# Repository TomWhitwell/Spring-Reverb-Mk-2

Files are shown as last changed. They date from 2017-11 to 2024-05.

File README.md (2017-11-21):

## Spring Reverb Mk 2

These are the design files for the Music Thing Modular Spring Reverb. 

[Full details about the module are in this rather long Medium post](https://medium.com/music-thing-modular-notes/everything-i-know-about-spring-reverb-1fb4b32abf87) 

You can [buy full kits for the Spring module here at Thonk](https://www.thonk.co.uk/shop/mtm-spring-reverb-mkii-kit/?utm_source=github), and [here's the kit for the expander](https://www.thonk.co.uk/shop/mtm-spring-expander-kit/?utm_source=github). 

# Issues and troubleshooting 
The quickest way to find solutions or report issues is [here in the issue log](https://github.com/TomWhitwell/Spring-Reverb-Mk-2/issues)

# In this repository you will find: 

[The Schematic PDF is here](https://github.com/TomWhitwell/Spring-Reverb-Mk-2/raw/master/Collateral/SpringReverbMk2-Schematic.pdf) 

Eagle CAD PCB files for:  
1. The main module, which contains two PCBs in the same file: SpringReverbRev2_combined
2. A plain PCB panel for the main module: SpringReverbRev2_panel
3. The PCB for the expander: Spring_Rev2_expander
4. A plan PCB panel for the expander: Spring_Rev2_expander_panel

The draft BOM is [here on google drive](https://docs.google.com/spreadsheets/d/1CzZeQc7hFVf5DQ_6vUL5soYb9Bh4oqvPB2Zx_D7NQ_I/edit?usp=sharing)

# License

Spring is Open Hardware
All hardware and software design in this project is Creative Commons licensed by Tom Whitwell: CC-BY-SA: Attribution / ShareAlike
If you use any work in this project, you should credit me, and you must republish any changes you make under the same license.
This license does permit commercial use of these designs, but consider getting in touch before selling anything.
This license does not permit you to use the name Music Thing Modular. Please do not use the name 'Spring' or 'Music Thing Modular' for any derivative works.

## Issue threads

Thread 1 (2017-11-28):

Low Volume / Short When Brick Inserted

junge1987, 2017-11-28:
I have double-checked all values and re-flowed all solder joints as well as verified OP-AMP orientation and checked for solder bridges.  Jumper is inserted in Brick Mode.  I have swapped TL074, TL072, and 78L05 with my private stock to verify functionality of IC's.  I have also verified orientation of Electrolytics.

When Belton Brick is inserted, it shorts out my rack's power supply upon power up (cycles on and off).

When I remove the Belton Brick, it power up (LED On, Signal Flowing).  Output is extremely low (like less than 5% of original)

Thonk-Steve, 2017-11-30:
Hi, do you also have a real spring tank?

junge1987, 2017-11-30:
I unfortunately do not.  Both of my guitar amps don't have built-in tanks either.

TomWhitwell, 2017-11-30:
This sounds obvious, but do you have the Brick the correct way around - matching the silkscreen on the PCB

junge1987, 2017-11-30:
Yes.  I have it the right way matching the screen.

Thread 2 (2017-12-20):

tank working but only distorded sound on outputs

kluber, 2017-12-20:
Hi Thom I hope you can help as I'm facing a really weird issue here.
I've built the spring without any problem following step by step the building guide.
I have some experiences in soldering and DIY _(TTSH, Yocto, Mutant Hihat and Bassdrum to name a few)_.

I'm gonna try to describe the best I can the symptoms but first here are some details

A) The module turns on.
B) If I turn the Blend knob the led lights up progressively.
C) The CV Input works.
D) The Tilt circuit seems to work.
E) The Feedback Input works so i can blend two signals coming from Input and Feedback
F) The brick/tank Jumper is set to Tank.
G) The RCA Connectors are not mounted on the front plate.
H) It's hooked up to a brand new Accutronic 9EB2C1B tank only _(no brick installed)_.
I) The tiny smt like pads for grounding the IC103 pin 9 has been soldered.
J) I have already changed the 5 ICs on the module _(cheap and easy check)_.
K) I have checked the resistors values and the polarity of the capacitors and the ICs.
L) Unfortunately I don't own an oscilloscope but a multi-meter.
M) The RCA cable is home made but I've already checked the continuity and it seems fine to me.
N) I have resoldered most of the circuit to prevent any cold joint.

Most importantly, the module has worked pretty fine the day I finished to build it and then the next day it wasn't working anymore but with the following symptoms :

From the outputs _(Wet/Blend)_ I get a _(not really loud)_ distorted sound of the dry signal but no reverberated. If I touch the spring inside the tank I can hear the reverb _(clear and loud)_ without the dry signal tho. As well, the feedback doesn't work.

I'm trying to figure out what is going on and precisely where to look. Since the Signal is not going to the Tank I guess something is wrong with either the Spring Drive Circuit or either somewhere around the NE5532 chip. Also I haven't checked the 78L05 but from your schematics it looks like it is used specifically for powering the Brick.

Anyway it is a long post and I should wait for your answer first ! ;-)

So Tom _(or someone)_ do you have any idea in what to check or where or who could be the culprit?
Thanks in advance!
Cheers!

Vincent

kluber, 2017-12-20:
Hey Tom I wasn't expected an answer that fast! ;-)
First of all thank you!
Also while you were answering me, I found out I hooked up the Tank in a wrong way... So I've edited the message below and change the symptoms maybe you could read them again (sorry...)

kluber, 2017-12-23:
Hi Tom I wanted to let you know what was the issue after all for people who might encounter those symptoms.
I've tracked the whole circuit and trying to figure out what in the hell was going on. In this end I've just realized one side of a coil of the spring tank was broken. I've lost a lot of time presuming the tank was ok since it was brand new.

Solved!

Cheers!

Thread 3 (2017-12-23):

I'd like to add Feedback to my mkI Spring Reverb

MickGlossop, 2017-12-23:
I have an new mkII kit to build, but i'd like to add the feedback function to my mk I unit.

Would that be an easy mod?

Mick

TomWhitwell, 2018-01-03:
It's very easy to patch using a mixer and a couple of mults or stackables, but I'm not sure how you'd do it in the existing module.

MickGlossop, 2018-01-04:
Thanks Tom. I thought as much. I've successfully patched an external solution using a mult and an attenuverter, for the +/- feedback option.

Closed 2018-01-03.

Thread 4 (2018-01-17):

Works great with tank, brick causes low-speed oscillation and distortion

rfcampbell, 2018-01-17:
Not using expander, jumper set correctly to "brick" position.

Wet and dry outputs both involve a fluctuating, heavily distorted sound.

https://youtu.be/AgYhhPH3KQ8

TomWhitwell, 2018-01-17:
Sorry to hear that, I've never heard one sounding like that before. Go through some standard troubleshooting - check all the solder points, check orientation of chips and the brick, check the voltages with a multimeter. My hunch is that it is a soldering issue somewhere. You may be able isolate the trouble point by checking the x-fade is working as expected - that rules out a certain portion of the board.

rfcampbell, 2018-01-18:
Thanks. Although the joints all looked good, I touched them up and now it works as it should. Sorry for the trouble!

Closed 2018-01-18.

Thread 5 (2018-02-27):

No signal from input/feedback, either dry or to tank

danismithcheapdeals, 2018-02-27:
Hi Thom,

I built the spring reverb last week but can't get any dry/wet signal from the input. I can hear the tank itself if I move it or turn up the trimmer to oscillation. X-fade input seems to work. I've tried swapping over the ICs and checked over the solder joints to see if any were bridged/cold. I've had a look over the schematics to try and see what the signal path is.

Details of the problem:
-I get regular signal through x-fade, can be turned down using wet control
-I get VERY quiet, nearly inaudible signal through Feedback input
-I get basically inaudible/no signal through input.

-I get signal FROM the tank but nothing going in
-If I turn the trimmer to the point of oscillation and then slightly backwards I can hear Feedback
signal faintly through the spring

-The dry/wet control only seems to work as a Wet/xfade level - NO dry signal at all
-LED on front panel works, not sure if vactrol is working

-no response from feedback or tilt controls

The fact that the crossfader only works on one side makes me think there is an issue with the vactrol, do you have any ideas about what might be the issue?

Thanks,
Dani

oliverlyu, 2018-07-10:
I have the exact same issue, any thoughts as to what this might be?

danismithcheapdeals, 2018-07-10:
Have been trying to get this to work on and off over the last few months but nothing yet. If anyone has any suggestions would be greatly appreciated!

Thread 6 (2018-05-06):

Distorted output and no Reverb

danfastlikeflan, 2018-05-06:
Hi Tom,
Hopefully you can provide some insight. I have already reflowed all joints and checked for solder bridges. Here are some symptoms:

-Module turns on and behaves the same with the jumper in either position and without the jumper on at all
-The led is max brightness with all knobs full clockwise and then gets very dim when the cv knob is about 10% and then will get progressively brighter when rotating the main knob
- with the feedback switch off, the output is very quiet and get louder until feedback is turned up to about 10% and turns into distortion any farther than that
- The three feedback switches do provide three different tones
- the wet output is always completely quiet
- tilt has no noticeable effect

Any help is appreciated.
Thanks,
Daniel

TomWhitwell, 2018-05-06:
That's quite a baffling selection of symptoms.
The main LED sounds correct
You can check the crossfade independent of the spring reverb by patching another signal into x-fade and checking that crossfade is smooth.
Tilt acts on the send to reverb, so should only be audible in reverb tails
Distortion - have you calibrated the module - setting the trimmer so that it doesn't distort

Are you using Brick or Spring?

Jumper = no impact = that suggests a short or missing connection somewhere - perhaps upload high res pictures of the front and back of the boards.

danfastlikeflan, 2018-05-06:
Thanks for the quick reply. Here's a link to some pics: https://imgur.com/a/YYnqVJq.
I have tried both the spring and the brick but neither resulted in any reverb. Even plucking the tank does produce any sound. I tried testing just the crossfade but its still very distorted there is nothing audible until feedback is turned up a little, even with the feedback switch in the off position. The trim pot does not have any effect on the sound. After playing a little more with it, it seems like inverted feedback and no feedback sound the same.

TomWhitwell, 2018-05-06:
OK, so global problems like that might be...
An IC that is the wrong way around - perhaps a TL072 on the front (panel) board?
An IC that is not properly seated - so one leg isn't making a connection
A power issue; a missing/reversed diode.
You can see the schematic here: http://musicthing.co.uk/collateral/SpringReverbMk2-Schematic.pdf

danfastlikeflan, 2018-05-06:
One of the diodes was backwards. Thanks so much for the help!

Closed 2018-05-07.

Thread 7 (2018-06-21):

No sound from spring tank

dorkajef, 2018-06-21:
Hello,
Just tested the module and everything seems to be ok, but the sound what should come from the spring reverb tank is only a buzz sound (no signal thru that side).
I think it´s because I did use some bigger capacitors (and had some difficulties to fit them -> so I think I did broke the PCB where the 22uf cap is). Can I solder some jump wires to (and from) the 22uf cap?

Best regards
Thomas

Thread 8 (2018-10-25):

Very High-Pitched Sound when using in-phase Feedback

Triscus, 2018-10-25:
Yesterday I built the Spring Reverb and the Expander with brick and a 9EB2C1B  Spring. The module was calibrated like described in the manual and working fine so far.

I only noticed one issue: When the in-phase feedback is used and the EQ/Tilt Knob is set to trebles (more to the right, depending on the feedback level), at some point the module suddenly makes a really unpleasant loud and high-pitched sound. It doesn't build up like the feedback, it just appears. It stops when turning the tilt or the feedback knob down a bit and happens only when the Spring is used.

Turning down the trim pot helps, but if I want to EQ the trebles I need to turn the trim pot the whole way down and have little to no effect left.

Any Idea how the sound can be avoided? I just want to be sure this isn't happening by accident.

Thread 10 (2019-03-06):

Low volume Brick

raimund, 2019-03-06:
I hav the mk2 Spring reverb with the expander.
The Tank works fine, but the Brick is a lot more quiet.
Is this a normal behaviour?  I have the BTDR-2H Brick.
Or where should I check the soldering (already resoldered but still quiet).

sinesurf, 2024-05-07:
Hello did you ever figure this out?  I'm having the same problem: With input at full volume, Tank sounds great, Brick is quiet.

Thanks

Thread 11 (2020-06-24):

Good-sounding mods for Spring Reverb from Anders Mikkelsen

TomWhitwell, 2020-06-24:
Source: https://www.facebook.com/groups/436675570022014/permalink/1144002955955935/

When adjusting the tank drive level, I didn't manage to get more than about 500 microamperes RMS through the transducer, before serious distortion appeared. This is approximately 16 dB below the recommended drive level. This has to be compensated for by adding gain in the recovery amplifier, and the tank sensitivity to microphonics and external fields will therefore be degraded by the same amount. The distortion was caused by the driver op-amp running out of voltage headroom. Further investigation showed that the combination of this reverb tank and the RC network across it has a strong resonance around 10 kHz, where the impedance peaks at 8 kohm or so. I replaced the 3.3 nF capacitor (C108) with a 1.5 kohm resistor, to form a simple pole around 6 kHz. This limits how high the impedance of the tank can rise at high frequencies, and allows a higher drive level within the voltage rails of the op-amp.

Secondly, the recovery amplifier has a pole (lowpass) at 3.3 kHz formed by R109 and C110. This cuts too much of the high-end in the reverberation signal for my liking, so I replaced C110 with 470 pF. There's little benefit to going above 10 kHz, so ideally a 680 or 820 pF cap should be used here. I only had 470 pF in the right package, so I ended up at 16 kHz.

There's no low-pass filtering of the signal going into the reverb driver. To avoid spending headroom on processing frequencies that won't make it through the springs anyways, I added a pole to the reverb send signal, 1.5 nF across R6.

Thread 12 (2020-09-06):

no reverb

mach-spring, 2020-09-06:
Hi, my module looks fine - LED looks good (fades in as I turn the big knob). But there is no reverb. When I turn the big knob the signal out just becomes weaker (to about half). When Tilt is turned up also the sound slightly changes. Thanks for your help!

TomWhitwell, 2020-09-06:
Hi, sorry to hear that.
Check you have installed the jumper and that the connections to the spring tank look good.

mach-spring, 2020-09-06:
Hi, thanks for your quick answer.

Could it be because the voltage regulator got too hot?

I measured it though: with red to ground both sides (input and output) read appr. 0.66.

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

TomWhitwell, 2020-09-06:
Ok, so you definitely have a power problem - you should have +12 on one side and +5 on the other

TomWhitwell, 2020-09-06:
Ok, so you definitely have a power problem - you should have +12 on one side and +5 on the other. Is the polarity correct - is it definitely the 78L05, not a transistor?

TomWhitwell, 2020-09-06:
Ok, so you definitely have a power problem - you should have +12 on one side and +5 on the other. Is the polarity correct - is it definitely the 78L05, not a transistor?

mach-spring, 2020-09-08:
Ok. I rebuilt the back board and this one now works so I’m a bit closer to know where to look. I don’t really know how to measure the ‚special‘ components so I’ll start exchanging things. I’ll close this thread as soon as the culprit is found.

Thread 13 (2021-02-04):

Module made a spark and stopped working

smnkjr, 2021-02-04:
hi everyone

I just finished this module which was my first build ever. A lot of fun to build!

When I turned on the module, everything seemed to be working, with sound through, led etc.
However at first I didn’t get any reverb through. I found at that when I made to tip of the rca cable touch the side of rca connector I got the reverb. It was probably my tank that was acting strange.
In doing this, I touched some electronics with the module powered on, and this made a small spark, and after that nothing works.

Do any of you have any idea which parts have been broken?

Cheers
Simon

this was where I touched it with the rca cable when it sparked:
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

finished build:
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
Finished build:
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

TomWhitwell, 2021-02-04:
Hi, sorry to hear that - it's always hard to diagnose that kind of issue.
You could start with the TL074 on the back near the phono jacks. If you don't have a spare, you could swap the two TL074 chips to see what happens - one does the drive/recovery, the other does the crossfade circuit.
However, that doesn't address the original no reverb problem - what tank are you using? Do you also have the 'brick'?

smnkjr, 2021-02-05:
Hi Tom

Thank you for replying this quickly :)
I don't know the brand of the tank, but it isn't anything special. I don't have the 'brick'. I think it's quite possible that the issue with the lack of reverb, came from the tank / cable, so I would be sure that there was a problem with the module, before i tried exchanging the other parts.

I tried swapping the TL074's with no luck. Would it be common for them to get broken from a shortcurcuit? And in that case, would It make sense to buy some new ones?
I checked with my voltmeter, and it made a beep when i connected the +12v with -12v, but no connection between -12v/+12v and ground.

Cheers

TomWhitwell, 2021-02-05:
Did you buy the tank separately? There are quite specific requirements for the tank - details here:
https://medium.com/music-thing-modular-notes/everything-i-know-about-spring-reverb-1fb4b32abf87
and here:
https://musicthing.co.uk/pages/spring.html

The chips could potentially be damaged if the short circuit sent a high voltage somewhere it wasn't expected.

The +12 - -12 connection doesn't sound good at all, but maybe remove all the the chips and separate the boards, then do the same test. A fried chip might have a short inside it, potentially.

smnkjr, 2021-02-05:
I had the tank laying around already. But now I think I will get a new tank instead, that fits the specifications.

I just made some progress! I tried removing both th TL074's, and that removed the +12 - -12 connection. Then I found out that one of the TL074's made the connection, but the other one didn't.
I'll order some new TL074's from thonk right away, and try it out with a different tank :)

TomWhitwell, 2021-02-05:
Great, that sounds promising - some spring tanks have quite different ground connections, for example, which makes them not work properly. I'll close this now, but come back if you still have trouble.

Closed 2021-02-05.

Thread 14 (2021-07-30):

Reverb sounds better when in/out of tank are reversed

iamdamosuzuki, 2021-07-30:
Is there any reason that this would happen? I'm using an Accutronics 9EB2C1B from Thonk. Is it possible for the tank to be reversed internally somehow?

The reverb is louder, more sustained, and more pleasant if I reverse the cables. Might I have messed something up?

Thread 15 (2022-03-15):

No feedback

ricoloverde, 2022-03-15:
Hi, I built the Spring Mk2 for my Bugbrand system and everything seems to be working but the feedback. The system has banana jacks and runs on +/-15v. I have built a few of these over the years and never had any troubles but those were all for eurorack. Kind of stumped on this one. Thanks in advance for any help!

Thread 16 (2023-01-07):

Dimensions pcb

jojo-monk, 2023-01-07:
Hello,
I want to have a pcb made from the gerber file, but when I transfer it to jlcpcb, the site indicates inconsistent (50*50mm) or zero dimensions. Is it normal?

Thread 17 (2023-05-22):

Current PCB design RCA connector is no longer manufactured

aireilly, 2023-05-22:
https://www.mouser.ie/ProductDetail/16PJ092R-E
https://no.rs-online.com/web/p/rca-connectors/1248889
https://ie.farnell.com/lumberg/1552-02-v-black/rca-connector-rcpt-1pos-8-3mm/dp/2677776

No longer manufactured.

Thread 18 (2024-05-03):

Issue with PCB trace to expander header (REV2.1 combined)

misterpulcri, 2024-05-03:
In the SpringReverbRev2.1combined board the PCB trace falls sort of reaching the expander header pin 1

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

As I am using the expander in lieu of the PCB mpunted RCA connectors this resulted in no signal being sent to the tank. I was able to work arounf this by soldering a wire between pin 1 and one of the ring PCB holes for the send RCA connector.

TomWhitwell, 2024-05-03:
Apologies - have pushed a new Eagle file and gerbers

Closed 2024-05-03.

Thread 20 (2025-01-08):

Spring expander - MTA cables don't fit

geckohooks, 2025-01-08:
Got 3/4 way through building spring expander and had this issue:
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
The MTA cables don't fit the Spring sockets - the ridges seem to be in the wrong place! Anyone else had this? Any advice on what to do next? Can I break the ridges off for example?

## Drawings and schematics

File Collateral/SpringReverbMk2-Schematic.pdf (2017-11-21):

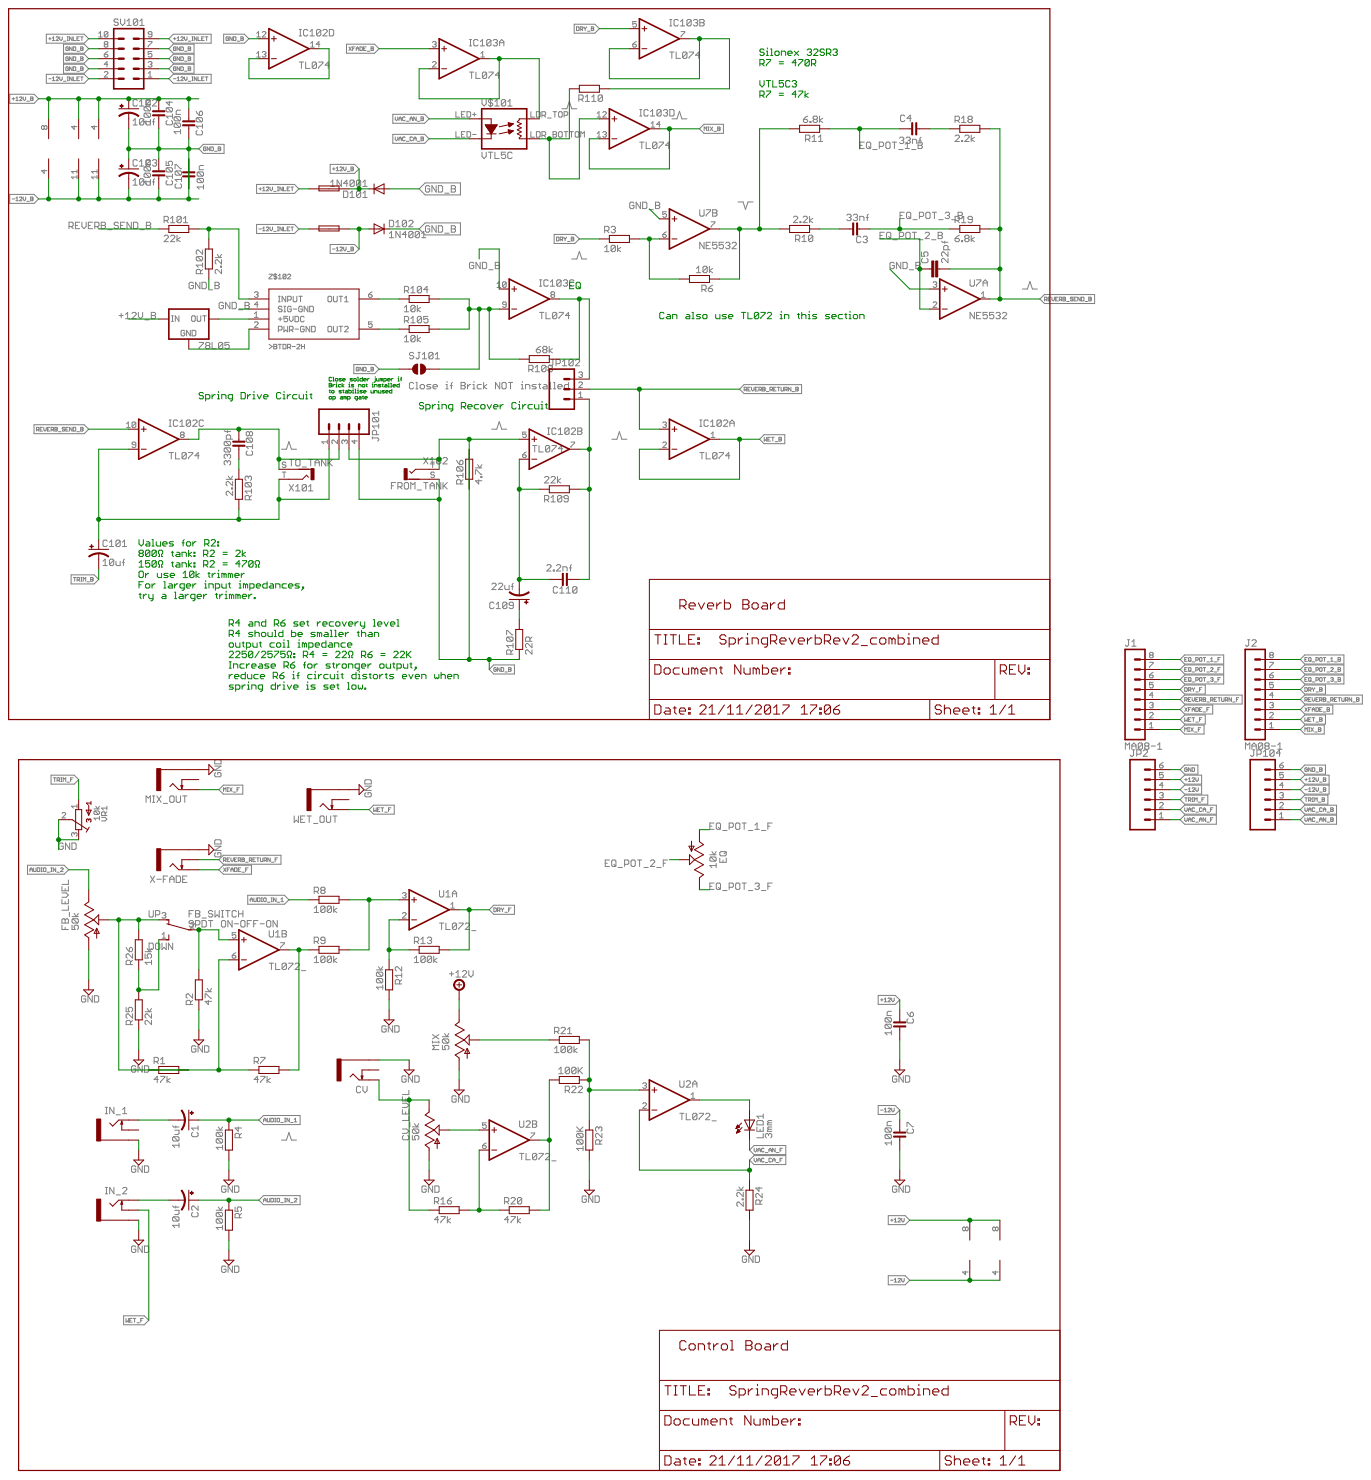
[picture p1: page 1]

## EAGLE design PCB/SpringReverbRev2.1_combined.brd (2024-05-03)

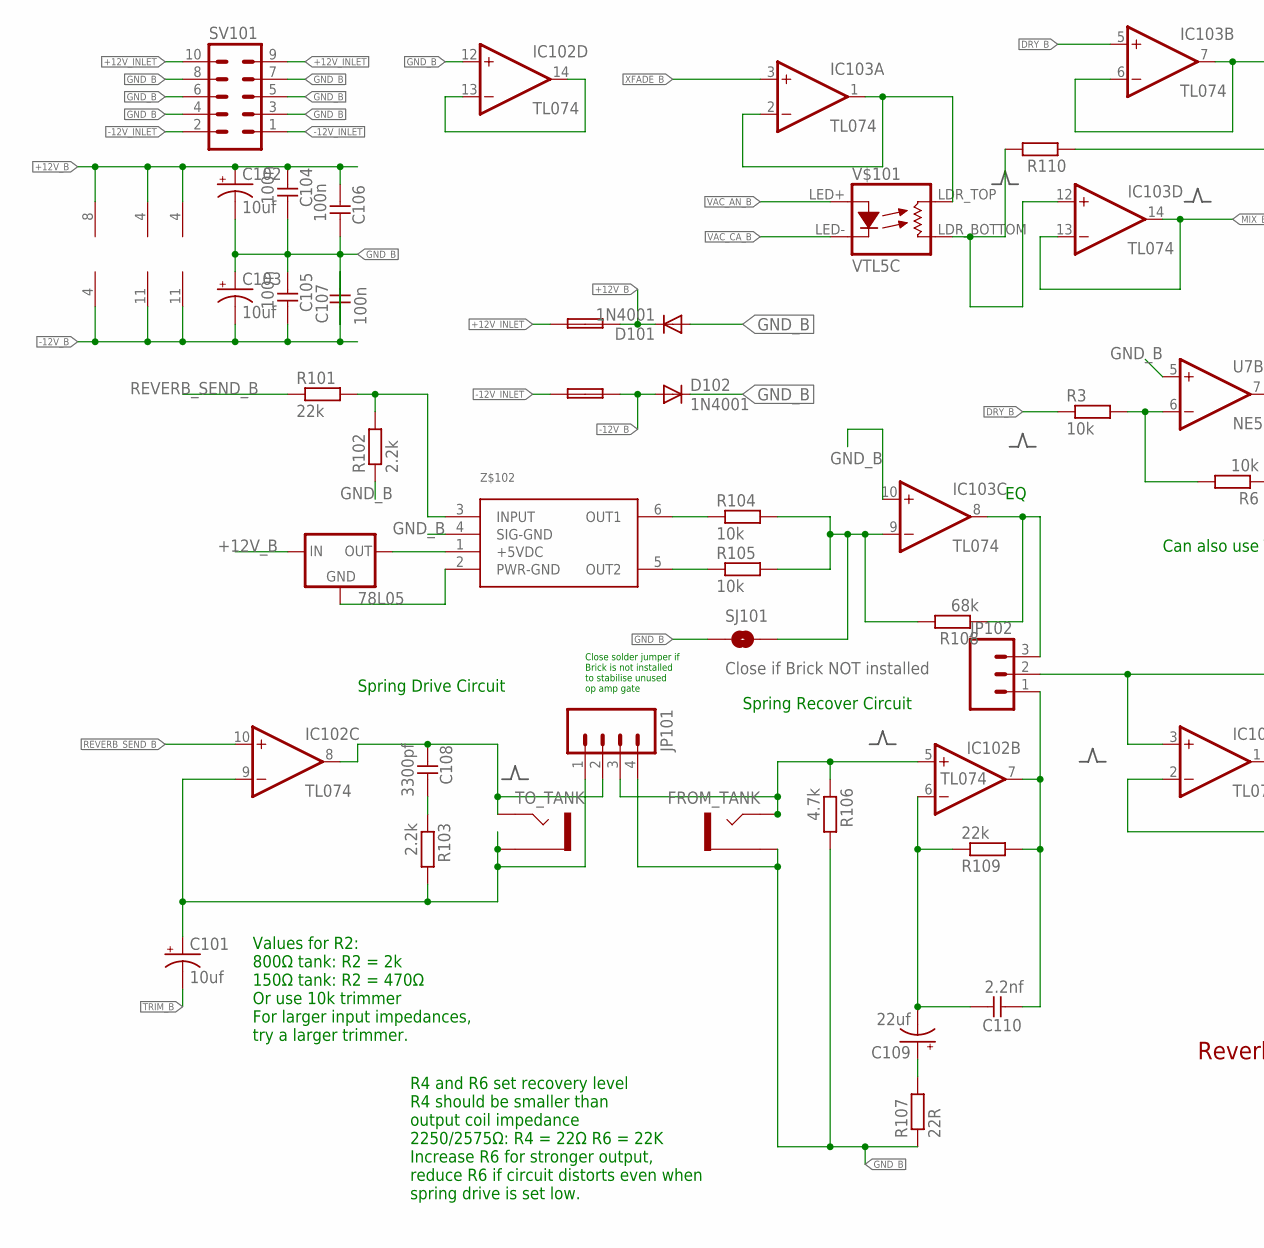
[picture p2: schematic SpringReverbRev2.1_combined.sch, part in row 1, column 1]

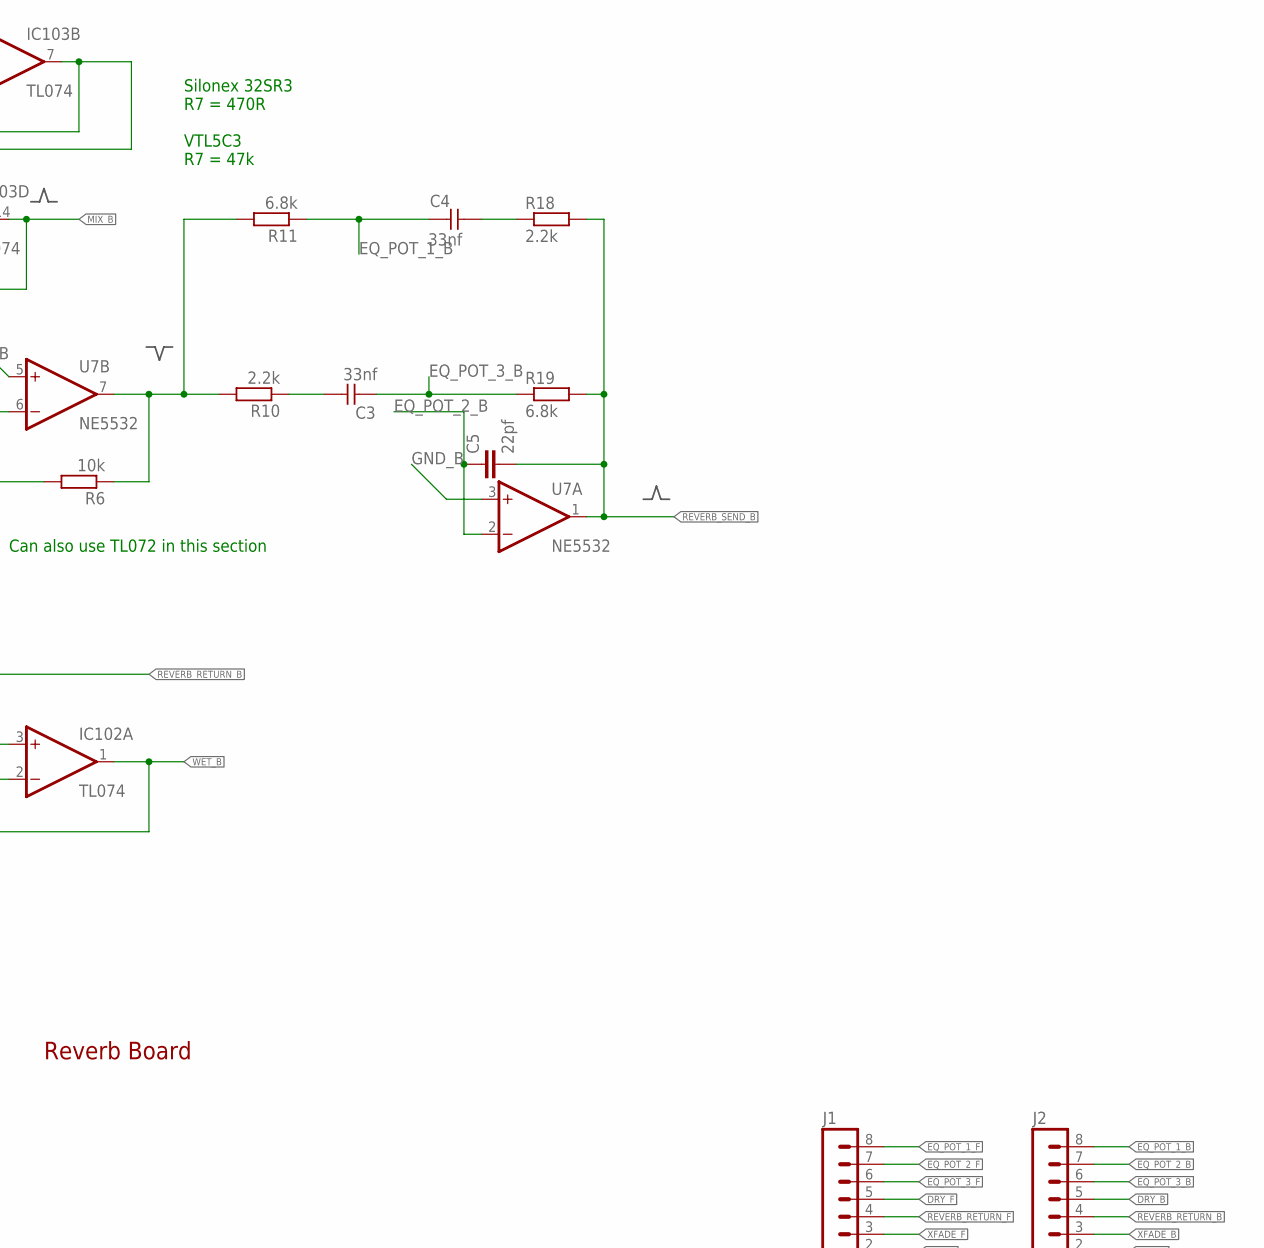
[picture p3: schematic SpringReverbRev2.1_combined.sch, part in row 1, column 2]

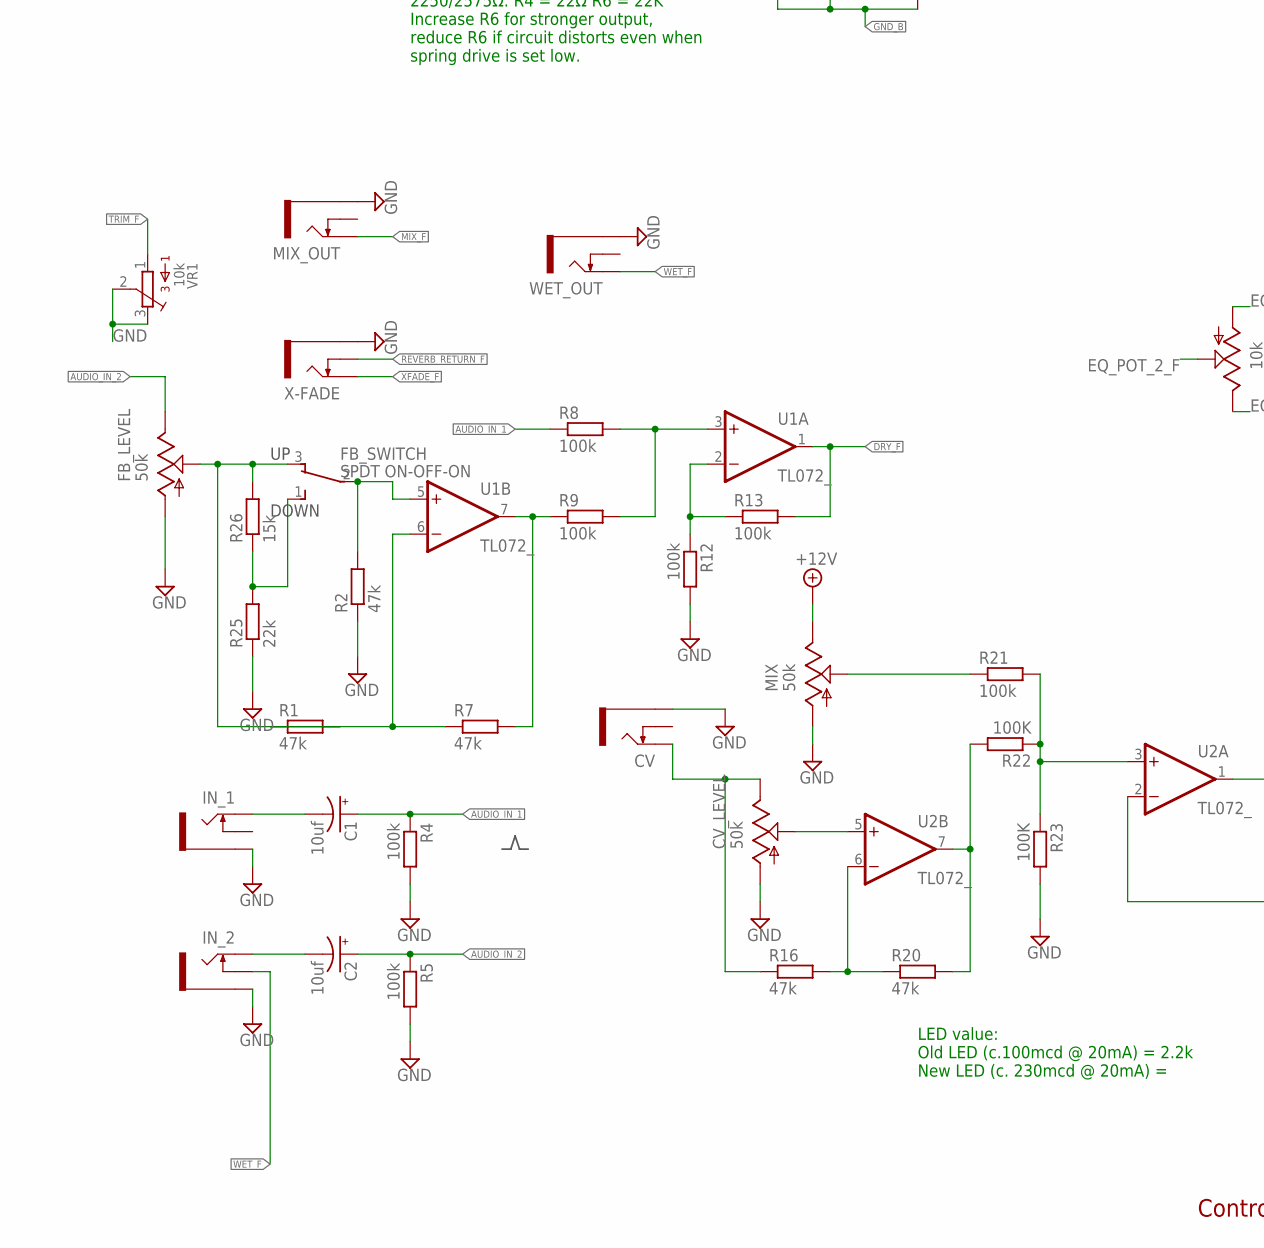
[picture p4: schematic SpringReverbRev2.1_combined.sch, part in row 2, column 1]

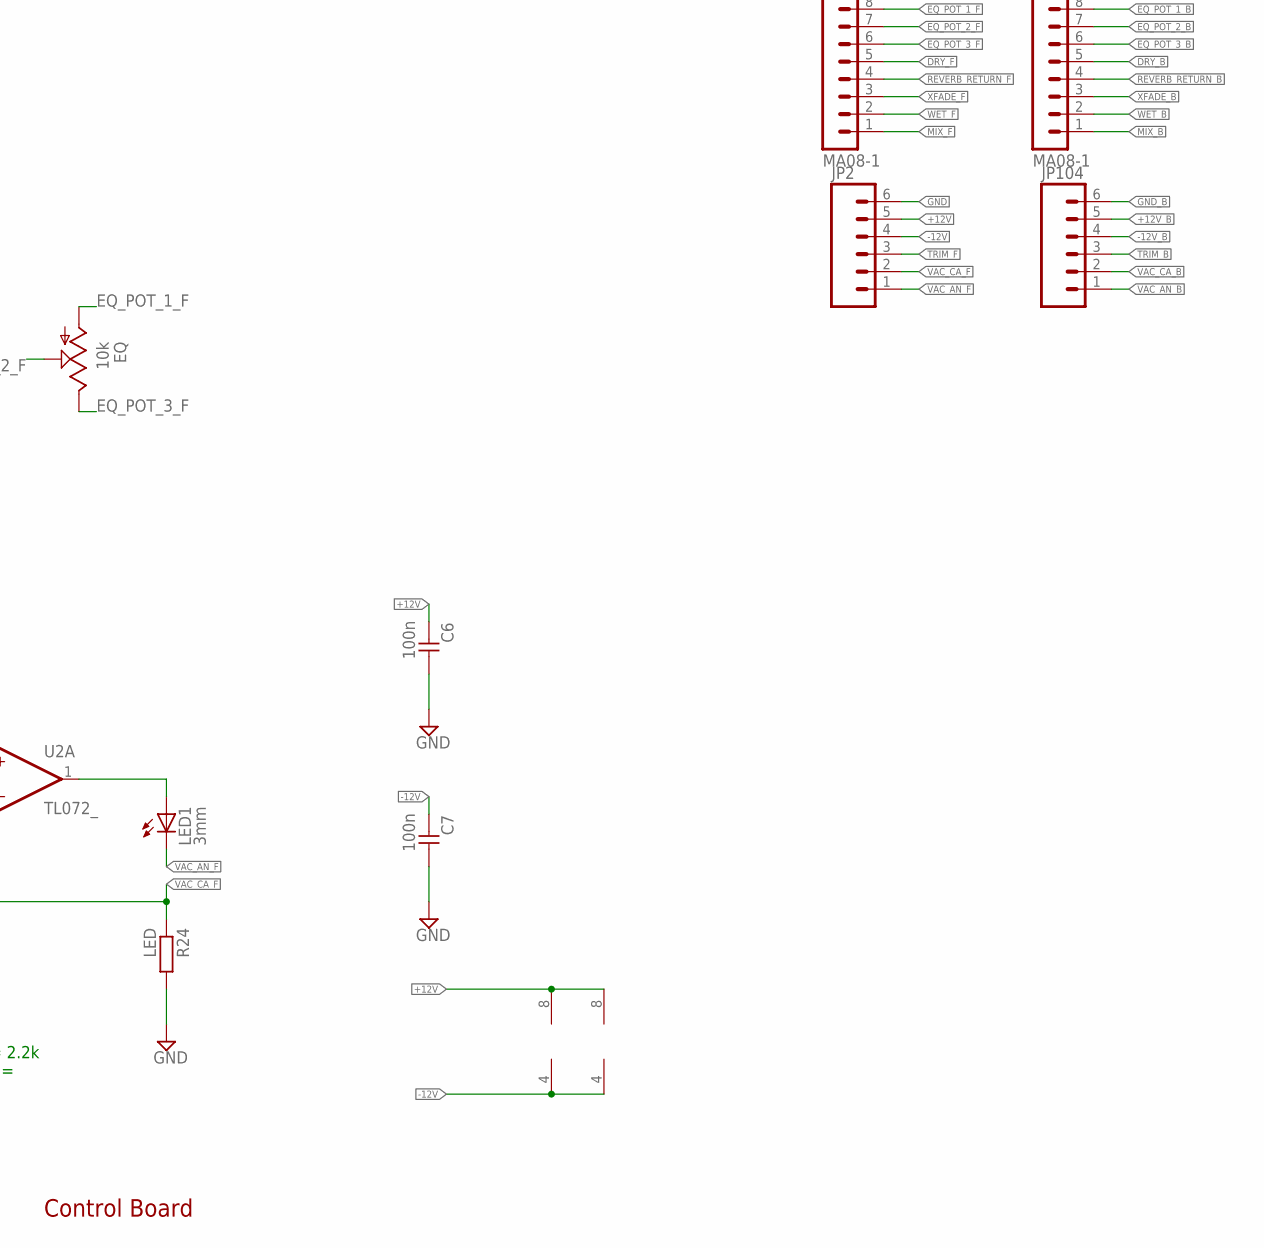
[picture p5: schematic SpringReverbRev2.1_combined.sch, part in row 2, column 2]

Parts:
78L05: 78LXX
C1, C2: 10uf; 050_020
C3, C4: 33nf; C050-024X044
C5: 22pf; 050X030_025
C6, C7, C104, C105, C106, C107: 100n; C050-024X044
C101, C102, C103: 10uf; CPOL-RADIAL-10UF-25V
C108: 3300pf; C050-024X044
C109: 22uf; CPOL-RADIAL-10UF-25V
C110: 2.2nf; C050-024X044
CV: THONKICONNNEW; WQP-PJ301M-12_JACK
CV_LEVEL: 50k; EVUF
D101, D102: 1N4001; DO41-10
EQ: 10k; EVUF
F101, F102: FUSE; C050H075X075
FB_LEVEL: 50k; EVUF
FB_SWITCH: SPDT ON-OFF-ON; SPDT-VERTICAL-TOP-SUBMINI-MULTICOMP
FROM_TANK: CUI-RCJ_RCA_PHONO
IC102, IC103: TL074; DIL14
IN_1, IN_2: THONKICONNNEW; WQP-PJ301M-12_JACK
J1, J2: MA08-1
JP2, JP104: M06SIP; 1X06
JP101: M04POLAR; MOLEX-1X4
JP102: M03LOCK_NO_SILK; 1X03_LOCK_NO_SILK
LED1: 3mm; LED3MM
MIX: 50k; EVUF
MIX_OUT: THONKICONNNEW; WQP-PJ301M-12_JACK
R1, R2, R7, R16, R20: 47k; 7MM_RESISTOR
R3, R6, R104, R105: 10k; 7MM_RESISTOR
R4, R5, R8, R9, R12, R13, R21: 100k; 7MM_RESISTOR
R10, R18, R102, R103: 2.2k; 7MM_RESISTOR
R11, R19: 6.8k; 7MM_RESISTOR
R22, R23: 100K; 7MM_RESISTOR
R24: LED; 7MM_RESISTOR
R25, R101, R109: 22k; 7MM_RESISTOR
R26: 15k; 7MM_RESISTOR
R106: 4.7k; 7MM_RESISTOR
R107: 22R; 7MM_RESISTOR
R108: 68k; 7MM_RESISTOR
R110: RESISTOR7MM; 7MM_RESISTOR
SJ101: Close if Brick NOT installed; SJ_2S-NOTRACE
SV101: 10_PIN_HEADER; MA05-2
TO_TANK: CUI-RCJ_RCA_PHONO
U1, U2: TL072_; DIL08
U7: NE5532; DIL08
V$101: VTL5C; VACTROL_COMPACT
VR1: 10k; BOURNS_3362P_TRIMMER
WET_OUT: THONKICONNNEW; WQP-PJ301M-12_JACK
X-FADE: THONKICONNNEW; WQP-PJ301M-12_JACK
Z$102: BTDR-2H

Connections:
+12V: C6.2, JP2.5, MIX.3 (E), U1.8 (V+), U2.8 (V+)
+12V_B: 78L05.IN, C102.1 (+), C104.2, C106.2, D101.C, F101.1, IC102.4 (V+), IC103.4 (V+), JP104.5, U7.8 (V+)
+12V_INLET: F101.2, SV101.9, SV101.10
-12V: C7.2, JP2.4, U1.4 (V-), U2.4 (V-)
-12V_B: C103.2 (-), C105.1, C107.1, D102.A, F102.1, IC102.11 (V-), IC103.11 (V-), JP104.4, U7.4 (V-)
-12V_INLET: F102.2, SV101.1, SV101.2
AUDIO_IN_1: C1.+, R4.1, R8.1
AUDIO_IN_2: C2.+, FB_LEVEL.3 (E), R5.1
AUDIO_IN_BUF: IC103.6 (-IN), IC103.7 (OUT), R110.1
BRK: IC103.8 (OUT), JP102.3, R108.1
CV_F: R20.2, R22.2, U2.7 (OUT)
DRY_B: IC103.5 (+IN), J2.5, R3.1
DRY_F: J1.5, R13.2, U1.1 (OUT)
EQ_POT_1_B: C4.2, J2.8, R11.1
EQ_POT_1_F: EQ.1 (A), J1.8
EQ_POT_2_B: C5.1, J2.7, U7.2 (-IN)
EQ_POT_2_F: EQ.2 (S), J1.7
EQ_POT_3_B: C3.2, J2.6, R19.1
EQ_POT_3_F: EQ.3 (E), J1.6
GND: C6.1, C7.1, CV.P$3_SLEEVE (SLEEVE), CV_LEVEL.1 (A), FB_LEVEL.1 (A), IN_1.P$3_SLEEVE (SLEEVE), IN_2.P$3_SLEEVE (SLEEVE), JP2.6, MIX.1 (A), MIX_OUT.P$3_SLEEVE (SLEEVE), R2.1, R4.2, R5.2, R12.2, R23.2, R24.2, R25.1, VR1.2, VR1.3, WET_OUT.P$3_SLEEVE (SLEEVE), X-FADE.P$3_SLEEVE (SLEEVE)
GND_B: C102.2 (-), C103.1 (+), C104.1, C105.2, C106.1, C107.2, D101.A, D102.C, FROM_TANK.GND1 (SLEEVE), FROM_TANK.GND2 (SLEEVE), IC102.12 (+IN), IC103.10 (+IN), JP101.4, JP104.6, R102.1, R106.2, R107.1, SJ101.1, SV101.3, SV101.4, SV101.5, SV101.6, SV101.7, SV101.8, U7.3 (+IN), U7.5 (+IN), Z$102.4 (SIG-GND)
MIX_B: IC103.13 (-IN), IC103.14 (OUT), J2.1
MIX_F: J1.1, MIX_OUT.P$1_TIP (TIP)
unnamed: C1.-, IN_1.P$1_TIP (TIP)
unnamed: C2.-, IN_2.P$1_TIP (TIP)
unnamed: MIX.2 (S), R21.1
unnamed: FB_LEVEL.2 (S), FB_SWITCH.3, R1.2, R26.2
unnamed: R1.1, R7.1, U1.6 (-IN)
unnamed: R7.2, R9.1, U1.7 (OUT)
unnamed: R8.2, R9.2, U1.3 (+IN)
unnamed: R21.2, R22.1, R23.1, U2.3 (+IN)
unnamed: R12.1, R13.1, U1.2 (-IN)
unnamed: CV.P$1_TIP (TIP), CV_LEVEL.3 (E), R16.1
unnamed: LED1.A, U2.1 (OUT)
unnamed: FB_SWITCH.1, R25.2, R26.1
unnamed: C3.1, R10.1
unnamed: C109.1 (+), R107.2
unnamed: C109.2 (-), C110.1, IC102.6 (-IN), R109.1
unnamed: CV_LEVEL.2 (S), U2.5 (+IN)
unnamed: C4.1, R18.1
unnamed: R16.2, R20.1, U2.6 (-IN)
unnamed: R3.2, R6.2, U7.6 (-IN)
unnamed: C108.1, R103.1
unnamed: 78L05.OUT, Z$102.1 (+5VDC)
unnamed: R104.1, Z$102.6 (OUT1)
unnamed: R105.1, Z$102.5 (OUT2)
unnamed: IC103.9 (-IN), R104.2, R105.2, R108.2, SJ101.2
unnamed: R6.1, R10.2, R11.2, U7.7 (OUT)
unnamed: R101.2, R102.2, Z$102.3 (INPUT)
unnamed: 78L05.GND, Z$102.2 (PWR-GND)
unnamed: IC103.12 (+IN), R110.2, V$101.LDR_BOTTOM (RES2)
unnamed: IC102.13 (-IN), IC102.14 (OUT)
unnamed: FB_SWITCH.2, R2.2, U1.5 (+IN)
R+: FROM_TANK.+V (TIP), IC102.5 (+IN), JP101.3, R106.1
REVERB_RETURN_B: IC102.3 (+IN), J2.4, JP102.2
REVERB_RETURN_F: J1.4, X-FADE.P$2_SWITCH (SWITCH)
REVERB_SEND_B: C5.2, IC102.10 (+IN), R18.2, R19.2, R101.1, U7.1 (OUT)
S+: C101.1 (+), IC102.9 (-IN), JP101.1, R103.2, TO_TANK.GND1 (SLEEVE), TO_TANK.GND2 (SLEEVE)
S-: C108.2, IC102.8 (OUT), JP101.2, TO_TANK.+V (TIP)
SPNG: C110.2, IC102.7 (OUT), JP102.1, R109.2
TRIM_B: C101.2 (-), JP104.3
TRIM_F: JP2.3, VR1.1
VAC_AN_B: JP104.1, V$101.LED+
VAC_AN_F: JP2.1, LED1.K (C)
VAC_CA_B: JP104.2, V$101.LED-
VAC_CA_F: JP2.2, R24.1, U2.2 (-IN)
WET_B: IC102.1 (OUT), IC102.2 (-IN), J2.2
WET_F: IN_2.P$2_SWITCH (SWITCH), J1.2, WET_OUT.P$1_TIP (TIP)
XFADE_B: IC103.3 (+IN), J2.3
XFADE_F: J1.3, X-FADE.P$1_TIP (TIP)
X_FADE_IN: IC103.1 (OUT), IC103.2 (-IN), V$101.LDR_TOP (RES1)

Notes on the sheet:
Control Board
Can also use TL072 in this section
Values for R2: 800Ω tank: R2 = 2k 150Ω tank: R2 = 470Ω Or use 10k trimmer For larger input impedances, try a larger trimmer.
Spring Drive Circuit
R4 and R6 set recovery level R4 should be smaller than output coil impedance 2250/2575Ω: R4 = 22Ω R6 = 22K Increase R6 for stronger output, reduce R6 if circuit distorts even when spring drive is set low.
Spring Recover Circuit
Reverb Board
Silonex 32SR3 R7 = 470R VTL5C3 R7 = 47k
Close solder jumper if Brick is not installed to stabilise unused op amp gate
LED value: Old LED (c.100mcd @ 20mA) = 2.2k New LED (c. 230mcd @ 20mA) =

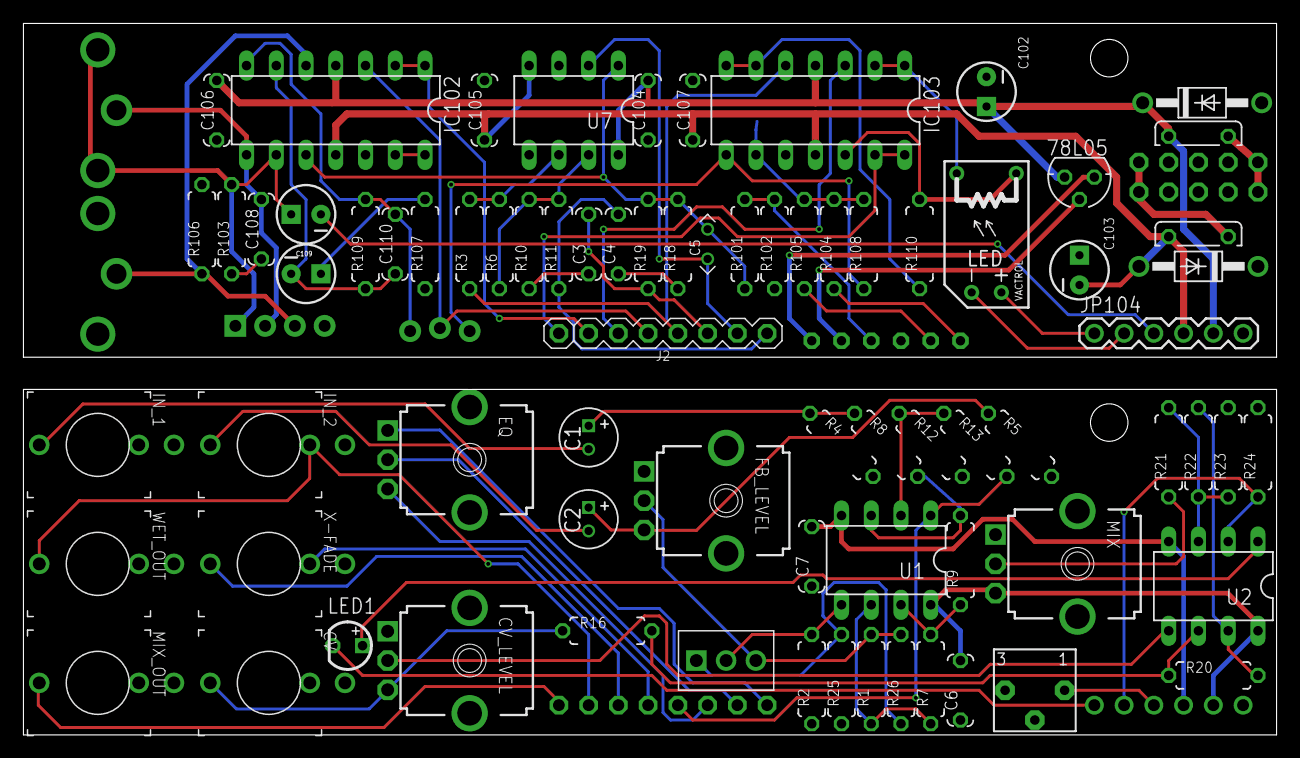
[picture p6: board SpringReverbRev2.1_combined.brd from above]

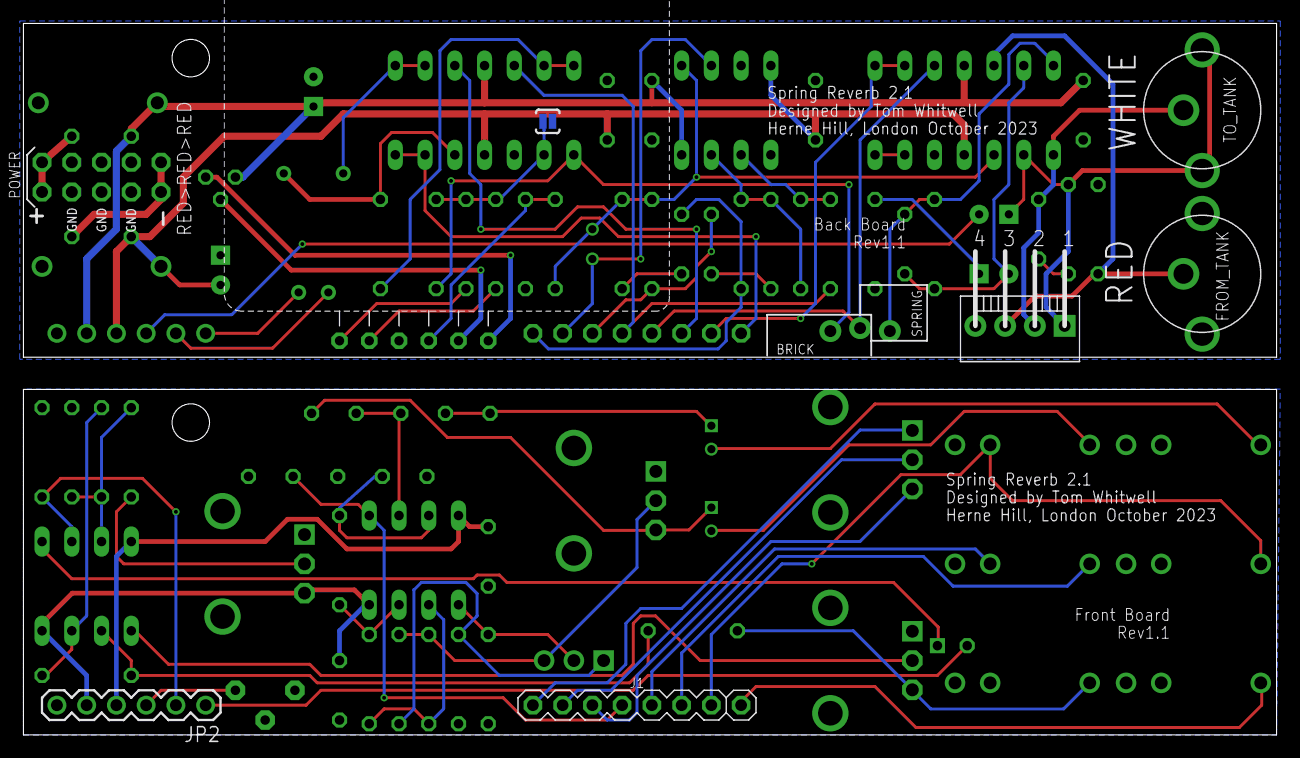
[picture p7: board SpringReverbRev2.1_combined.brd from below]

Board: 2 copper layers, 107.0 x 60.8 mm, 87 parts (9 on the bottom side), 71 nets.

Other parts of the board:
U$3, U$4: MOUNTING_HOLE

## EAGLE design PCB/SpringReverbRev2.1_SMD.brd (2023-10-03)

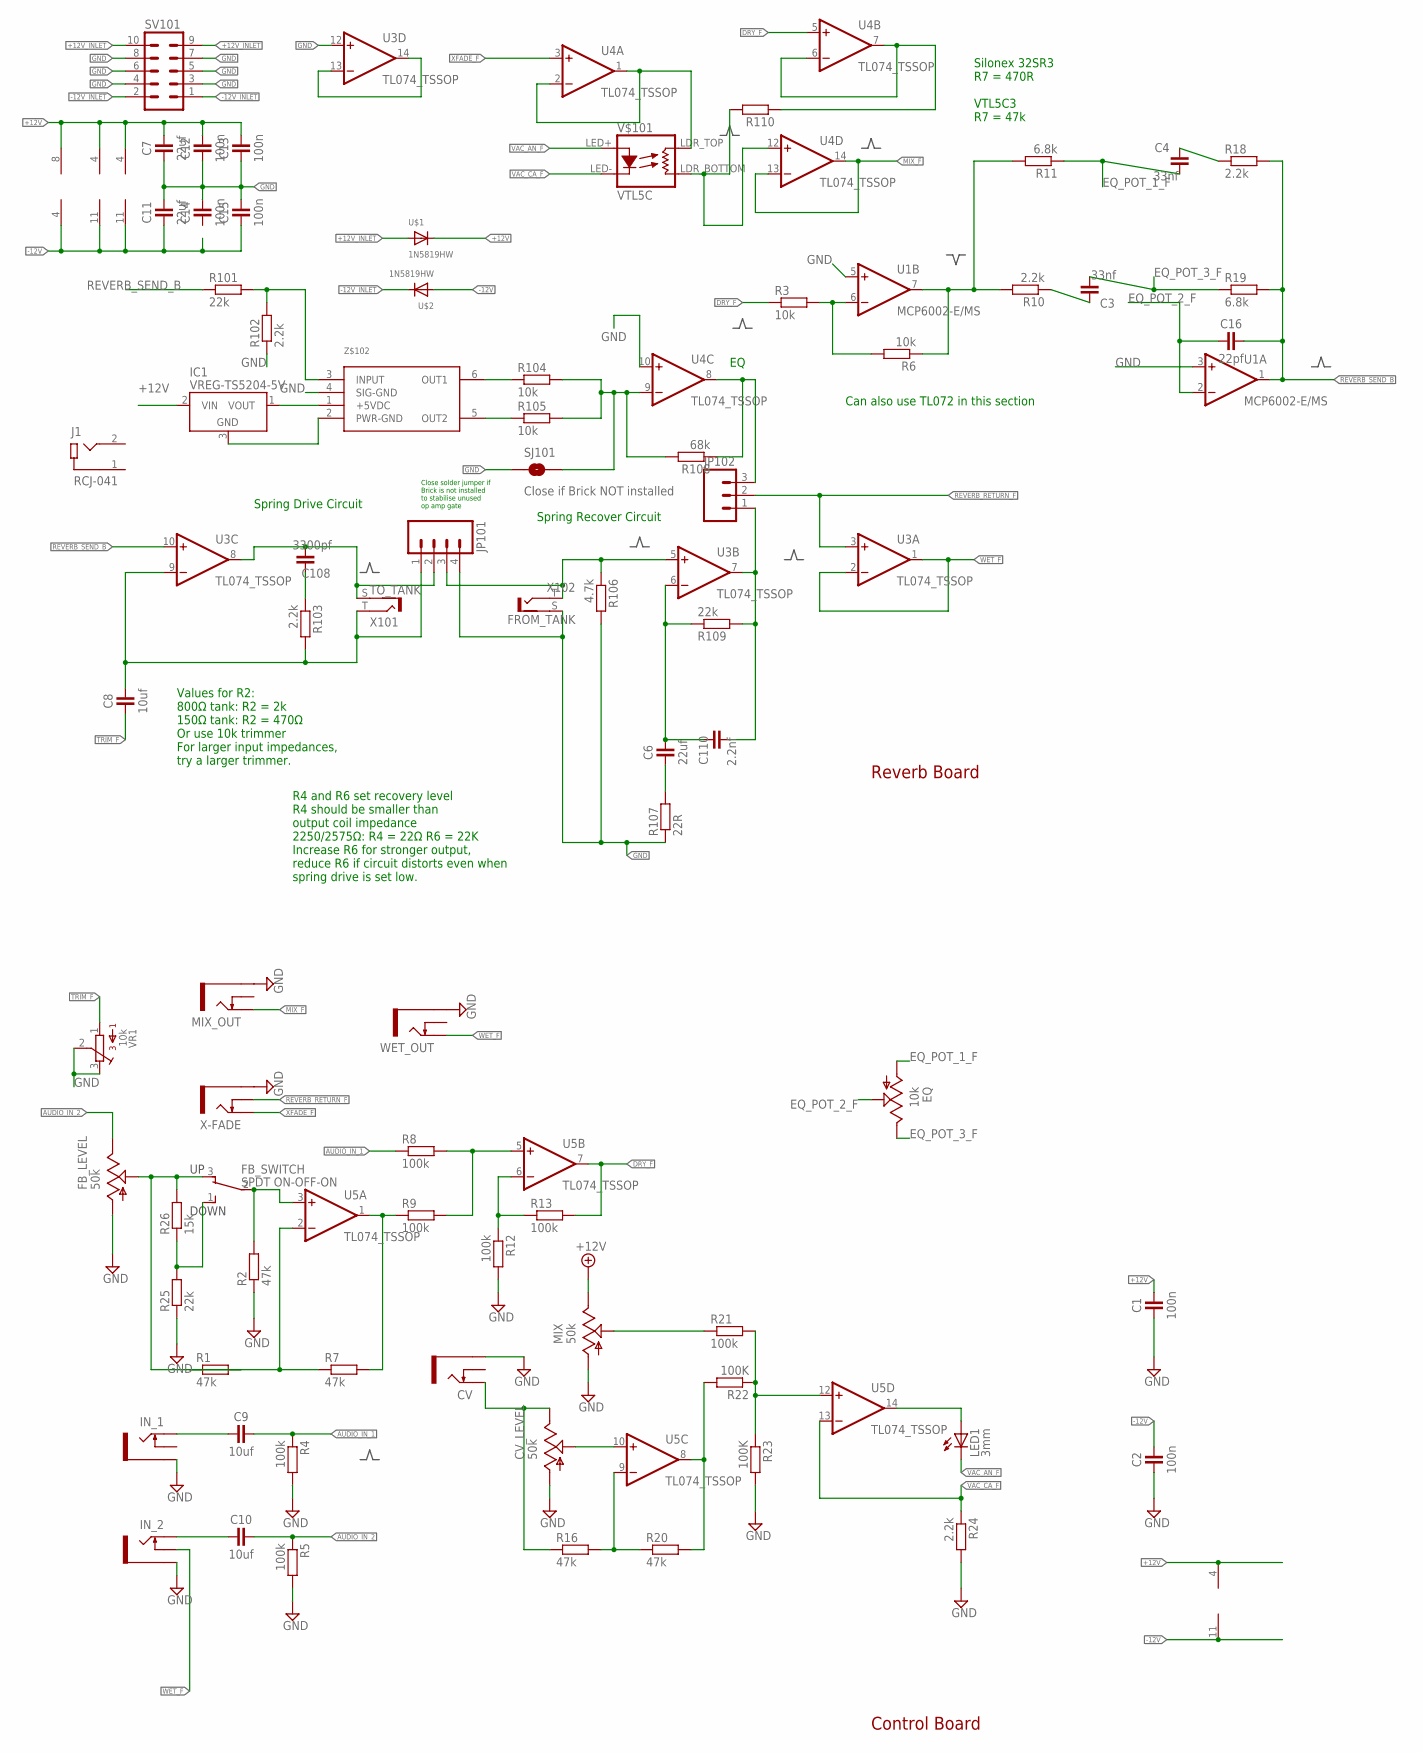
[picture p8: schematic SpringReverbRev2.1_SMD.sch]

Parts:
C1, C2, C12, C13, C14, C15: 100n; C0402
C3, C4: 33nf; C0402
C6: 22uf; C1210
C7, C11: 22uf; C1206
C8, C9, C10: 10uf; C0805
C16: 22pf; C0402
C108: 3300pf; C0402
C110: 2.2nf; C0402
CV: THONKICONNNEW; WQP-PJ301M-12_JACK
CV_LEVEL: 50k; EVUF
EQ: 10k; EVUF
FB_LEVEL: 50k; EVUF
FB_SWITCH: SPDT ON-OFF-ON; SPDT-VERTICAL-TOP-SUBMINI-MULTICOMP
IC1: VREG-TS5204-5V; SOT23
IN_1, IN_2: THONKICONNNEW; WQP-PJ301M-12_JACK
J1: RCJ-041
JP101: M04POLAR; MOLEX-1X4
JP102: M03LOCK_NO_SILK; 1X03_LOCK_NO_SILK
LED1: 3mm; LED3MM
MIX: 50k; EVUF
MIX_OUT: THONKICONNNEW; WQP-PJ301M-12_JACK
R1, R2, R7, R16, R20: 47k; C0402
R3, R6, R104, R105: 10k; C0402
R4, R5, R8, R9, R12, R13, R21: 100k; C0402
R10, R18, R24, R102, R103: 2.2k; C0402
R11, R19: 6.8k; C0402
R22, R23: 100K; C0402
R25, R101, R109: 22k; C0402
R26: 15k; C0402
R106: 4.7k; C0402
R107: 22R; C0402
R108: 68k; C0402
R110: RESISTOR-0402; C0402
SJ101: Close if Brick NOT installed; SJ_2S-NOTRACE
SV101: 10_PIN_HEADER; MA05-2
U1: MCP6002-E/MS; SOP65P490X110-8N
U3, U4, U5: TL074_TSSOP; SOP65P640X120-14N
U$1, U$2: 1N5819HW; SOD-123-EDITED
V$101: VTL5C; VACTROL_COMPACT
VR1: 10k; BOURNS_3362P_TRIMMER
WET_OUT: THONKICONNNEW; WQP-PJ301M-12_JACK
X101: TO_TANK; BTOR1
X102: FROM_TANK; BTOR1
X-FADE: THONKICONNNEW; WQP-PJ301M-12_JACK
Z$102: BTDR-2H

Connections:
+12V: C1.2, C7.2, C12.2, C13.2, IC1.2 (VIN), MIX.3 (E), U1.8 (V+), U3.4 (V+), U4.4 (V+), U5.4 (V+), U$1.C
+12V_INLET: SV101.9, SV101.10, U$1.A
-12V: C2.2, C11.1, C15.1, U1.4 (V-), U3.11 (V-), U4.11 (V-), U5.11 (V-), U$2.A
-12V_INLET: SV101.1, SV101.2, U$2.C
AUDIO_IN_1: C9.2, R4.1, R8.1
AUDIO_IN_2: C10.2, FB_LEVEL.3 (E), R5.1
AUDIO_IN_BUF: R110.1, U4.6 (-IN), U4.7 (OUT)
BRK: JP102.3, R108.1, U4.8 (OUT)
CV_F: R20.2, R22.2, U5.8 (OUT)
DRY_F: R3.1, R13.2, U4.5 (+IN), U5.7 (OUT)
EQ_POT_1_F: C4.2, EQ.1 (A), R11.1
EQ_POT_2_F: C16.1, EQ.2 (S), U1.2 (-IN)
EQ_POT_3_F: C3.2, EQ.3 (E), R19.1
GND: C1.1, C2.1, C7.1, C11.2, C12.1, C13.1, C14.2, C15.2, CV.P$3_SLEEVE (SLEEVE), CV_LEVEL.1 (A), FB_LEVEL.1 (A), IN_1.P$3_SLEEVE (SLEEVE), IN_2.P$3_SLEEVE (SLEEVE), JP101.4, MIX.1 (A), MIX_OUT.P$3_SLEEVE (SLEEVE), R2.1, R4.2, R5.2, R12.2, R23.2, R24.2, R25.1, R102.1, R106.2, R107.1, SJ101.1, SV101.3, SV101.4, SV101.5, SV101.6, SV101.7, SV101.8, U1.3 (+IN), U1.5 (+IN), U3.12 (+IN), U4.10 (+IN), VR1.2, VR1.3, WET_OUT.P$3_SLEEVE (SLEEVE), X102.S (2), X-FADE.P$3_SLEEVE (SLEEVE), Z$102.4 (SIG-GND)
MIX_F: MIX_OUT.P$1_TIP (TIP), U4.13 (-IN), U4.14 (OUT)
unnamed: C9.1, IN_1.P$1_TIP (TIP)
unnamed: C10.1, IN_2.P$1_TIP (TIP)
unnamed: MIX.2 (S), R21.1
unnamed: FB_LEVEL.2 (S), FB_SWITCH.3, R1.2, R26.2
unnamed: R1.1, R7.1, U5.2 (-IN)
unnamed: R7.2, R9.1, U5.1 (OUT)
unnamed: R8.2, R9.2, U5.5 (+IN)
unnamed: R21.2, R22.1, R23.1, U5.12 (+IN)
unnamed: R12.1, R13.1, U5.6 (-IN)
unnamed: CV.P$1_TIP (TIP), CV_LEVEL.3 (E), R16.1
unnamed: LED1.A, U5.14 (OUT)
unnamed: FB_SWITCH.1, R25.2, R26.1
unnamed: C3.1, R10.1
unnamed: C6.1, R107.2
unnamed: C6.2, C110.1, R109.1, U3.6 (-IN)
unnamed: CV_LEVEL.2 (S), U5.10 (+IN)
unnamed: C4.1, R18.1
unnamed: R16.2, R20.1, U5.9 (-IN)
unnamed: R3.2, R6.2, U1.6 (-IN)
unnamed: C108.1, R103.1
unnamed: IC1.1 (VOUT), Z$102.1 (+5VDC)
unnamed: R104.1, Z$102.6 (OUT1)
unnamed: R105.1, Z$102.5 (OUT2)
unnamed: R104.2, R105.2, R108.2, SJ101.2, U4.9 (-IN)
unnamed: R6.1, R10.2, R11.2, U1.7 (OUT)
unnamed: R101.2, R102.2, Z$102.3 (INPUT)
unnamed: IC1.3 (GND), Z$102.2 (PWR-GND)
unnamed: R110.2, U4.12 (+IN), V$101.LDR_BOTTOM (RES2)
unnamed: U3.13 (-IN), U3.14 (OUT)
unnamed: FB_SWITCH.2, R2.2, U5.3 (+IN)
R+: JP101.3, R106.1, U3.5 (+IN), X102.T (1)
REVERB_RETURN_F: JP102.2, U3.3 (+IN), X-FADE.P$2_SWITCH (SWITCH)
REVERB_SEND_B: C16.2, R18.2, R19.2, R101.1, U1.1 (OUT), U3.10 (+IN)
S+: C8.2, JP101.1, R103.2, U3.9 (-IN), X101.T (1)
S-: C108.2, JP101.2, U3.8 (OUT), X101.S (2)
SPNG: C110.2, JP102.1, R109.2, U3.7 (OUT)
TRIM_F: C8.1, VR1.1
VAC_AN_F: LED1.K (C), V$101.LED+
VAC_CA_F: R24.1, U5.13 (-IN), V$101.LED-
WET_F: IN_2.P$2_SWITCH (SWITCH), U3.1 (OUT), U3.2 (-IN), WET_OUT.P$1_TIP (TIP)
XFADE_F: U4.3 (+IN), X-FADE.P$1_TIP (TIP)
X_FADE_IN: U4.1 (OUT), U4.2 (-IN), V$101.LDR_TOP (RES1)

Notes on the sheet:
Control Board
Can also use TL072 in this section
Values for R2: 800Ω tank: R2 = 2k 150Ω tank: R2 = 470Ω Or use 10k trimmer For larger input impedances, try a larger trimmer.
Spring Drive Circuit
R4 and R6 set recovery level R4 should be smaller than output coil impedance 2250/2575Ω: R4 = 22Ω R6 = 22K Increase R6 for stronger output, reduce R6 if circuit distorts even when spring drive is set low.
Spring Recover Circuit
Reverb Board
Silonex 32SR3 R7 = 470R VTL5C3 R7 = 47k
Close solder jumper if Brick is not installed to stabilise unused op amp gate

Board: 2 copper layers, 79 parts (7 on the bottom side), 57 nets, no tracks yet.

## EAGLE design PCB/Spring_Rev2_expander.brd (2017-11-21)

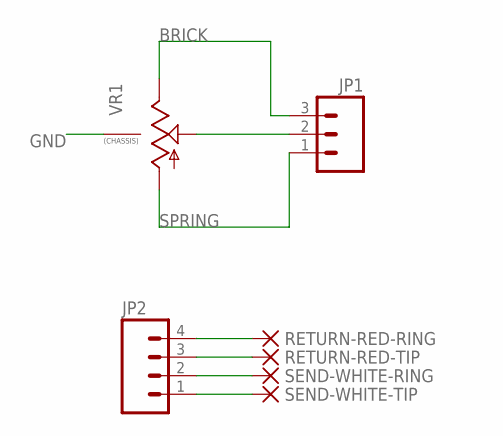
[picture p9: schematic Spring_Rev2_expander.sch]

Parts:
JP1: M03POLAR_LOCK; MOLEX-1X3_LOCK
JP2: M04POLAR_LOCK; MOLEX-1X4_LOCK
RETURN-RED-RING: PAD-1.00-2.00
RETURN-RED-TIP: PAD-1.00-2.00
SEND-WHITE-RING: PAD-1.00-2.00
SEND-WHITE-TIP: PAD-1.00-2.00
VR1: 9MM_SNAP-IN_POT_CHASSIS; 9MM_SNAP-IN_POT

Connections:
BRICK: JP1.3, VR1.3 (E)
GND: JP2.4, RETURN-RED-RING.1, VR1.CHASSIS1, VR1.CHASSIS2
OUT: JP1.2, VR1.2 (S)
R+: JP2.3, RETURN-RED-TIP.1
S+: JP2.1, SEND-WHITE-TIP.1
S-: JP2.2, SEND-WHITE-RING.1
SPRING: JP1.1, VR1.1 (A)

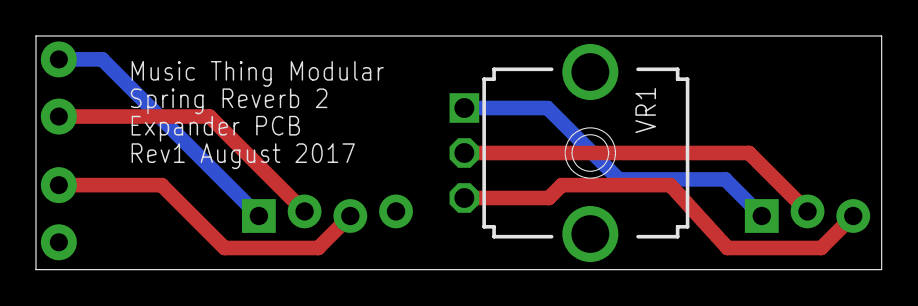
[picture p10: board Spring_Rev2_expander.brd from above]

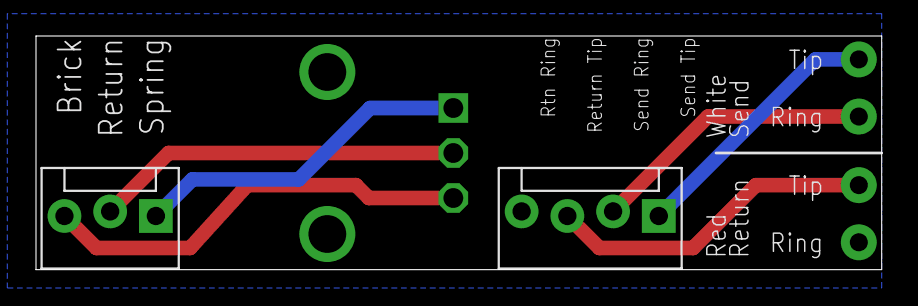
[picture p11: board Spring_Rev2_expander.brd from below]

Board: 2 copper layers, 47.0 x 13.0 mm, 7 parts (6 on the bottom side), 7 nets.

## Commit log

2017-11-21 remove draft bom
    [SpringReverbRev2_Bom_draft.csv]
2023-10-03 Updated for CUI RCJ RCA Phono Jacks
    [SpringReverbRev2.1_SMD.brd, SpringReverbRev2.1_SMD.sch, SpringReverbRev2.1_combined.brd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]
2024-05-03 Fixes #18
    [SpringReverbRev2.1_combined.brd, SpringReverbRev2.1_combined.sch]

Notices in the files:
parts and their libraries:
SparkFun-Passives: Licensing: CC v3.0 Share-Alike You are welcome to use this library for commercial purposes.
